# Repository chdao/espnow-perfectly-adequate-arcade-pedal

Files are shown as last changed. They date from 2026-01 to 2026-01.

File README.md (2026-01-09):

# ESPNow Perfectly Adequate Arcade Pedal

A wireless pedal system using ESP-NOW for low-latency communication between pedal transmitters and a USB HID keyboard receiver. Perfectly adequate for arcade gaming!

**Original Design**: This project is based on the [Perfectly Adequate Arcade Pedal (Wireless)](https://www.printables.com/model/1220746-perfectly-adequate-arcade-pedal-wireless) design on Printables. All initial ideas and the pedal model come from that design.

**PCB Project**: The custom PCB design is called **PanicPedal Pro** and includes an ESP32-S3-WROOM with automatic pedal detection. See `kicad-pcb/` for the KiCad project files and `esp32/panicpedal-pro/` for the firmware.

**⚠️ IMPORTANT CORRECTION**: The original schematic shows TP4056 OUT+ connected to the 3V3 pin. This is **INCORRECT** and can damage the ESP32. The TP4056 OUT+ must connect to **VCC** instead. See the [Wiring Diagram](#wiring-diagram) section below for the correct connections.

## Overview

This project consists of:
- **Transmitters**: ESP32-based pedal devices that send key press/release events via ESP-NOW
  - **FireBeetle 2**: `esp32/firebeetle2/firebeetle2.ino` - Configurable single or dual pedal mode
  - **PanicPedal Pro**: `esp32/panicpedal-pro/panicpedal-pro.ino` - Custom PCB with automatic pedal detection (1 or 2 pedals)
- **Receiver**: ESP32-S2/S3 device that receives ESP-NOW messages and types keys via USB HID Keyboard (`esp32/receiver/receiver.ino`)

**Note**: `espnow-pedal.cpp` is included as a reference file showing the original implementation. The actual project files are in the `esp32/` directory.

## Features

- **Low latency**: ESP-NOW provides fast, direct communication without WiFi connection
- **Multiple pedal modes**: Supports single pedal (LEFT or RIGHT) or dual pedal configurations
- **Automatic pedal detection** (PanicPedal Pro): Automatically detects whether 1 or 2 pedals are connected using NC (normally-closed) contacts - no manual configuration needed
- **Press and hold**: Keys stay pressed until pedal is released
- **Independent operation**: Both pedals can be pressed simultaneously
- **Battery efficient**: Includes inactivity timeout and deep sleep support
- **Automatic discovery**: No manual MAC address configuration needed - transmitters automatically discover receivers
- **Automatic reconnection**: Transmitters automatically reconnect to receivers after reboot
- **Slot management**: Receiver tracks available slots and only accepts transmitters when slots are available
- **Grace period**: 30-second discovery period after receiver boot for initial pairing and verification

## Hardware Requirements

### Recommended Boards

**Transmitters:**
- [FireBeetle 2 ESP32-E](https://www.dfrobot.com/product-2195.html) - Optimized for low power consumption, ideal for battery-powered pedal transmitters
- **PanicPedal Pro** - Custom PCB project with ESP32-S3-WROOM featuring automatic pedal detection (see `esp32/panicpedal-pro/README.md` for details)

**Receiver:**
- [ESP32-S3-DevKitC-1-N16R8](https://www.amazon.com/dp/B0CC8NYXRG) - ESP32-S3 board with native USB support for HID Keyboard functionality

### Transmitter
- ESP32 (tested with FireBeetle 2 ESP32-E and ESP32-S3-WROOM for PanicPedal Pro)
- Pedal switches (normally-open, connected to GPIO with pull-up)
- Optional: LED for status indication
- **PanicPedal Pro**: Uses NC (normally-closed) contacts for automatic detection of connected pedals

### Receiver
- ESP32-S2 or ESP32-S3 (for USB HID Keyboard support)
- USB connection to computer

## Pin Configuration

### Transmitter
- **Single Pedal Mode**: Connect pedal switch to GPIO 13
- **Dual Pedal Mode**: 
  - LEFT pedal: GPIO 13
  - RIGHT pedal: GPIO 14
- **LED**: GPIO 2 (optional)

**Pinout Reference**: See [FireBeetle 2 ESP32-E Pinout](docs/FireBeetle2_ESP32-E_Pinout.md) for complete pin details.

### Receiver
- Uses USB for communication (no GPIO pins needed for functionality)

## Wiring Diagram

### Transmitter Power Wiring (FireBeetle 2 ESP32-E)

**⚠️ IMPORTANT**: The TP4056 charging board OUT+ must connect to **VCC**, NOT 3V3!

```
TP4056 Charging Board          FireBeetle 2 ESP32-E
─────────────────────          ─────────────────────
OUT+ (red wire)    ──────────> VCC (or PH2.0 battery connector)
OUT- (black wire)  ──────────> GND
B+                 ──────────> 18650 Battery +
B-                 ──────────> 18650 Battery -
IN+                ──────────> Power Switch
IN-                ──────────> GND
```

**Why VCC and not 3V3?**
- **VCC** is the input voltage pin that accepts battery voltage (3.7-4.2V) or USB voltage (~4.7V)
- **3V3** is a regulated 3.3V OUTPUT pin - connecting 4-5V to it can damage the ESP32
- The FireBeetle's onboard regulator converts VCC to 3.3V internally

### Transmitter Signal Wiring

```
Left Pedal Switch (NO)  ───> GPIO 13
Left Pedal Switch (COM) ───> GND

Right Pedal Switch (NO)  ───> GPIO 14 (dual mode only)
Right Pedal Switch (COM) ───> GND

LED (anode)            ───> GPIO 2 (optional)
LED (cathode)          ───> GND
```

**Note**: The original schematic may show a "Mode Select Switch" on GPIO 26 for selecting between Bluetooth and ESP-NOW modes. This code uses ESP-NOW only, so that switch is not needed. Pedal mode (single/dual) is configured via the `PEDAL_MODE` define in the code.

**Note**: Switches should be normally-open (NO) type. The ESP32's internal pull-up resistors keep the pins HIGH when switches are open, and LOW when pressed.

## Setup and Usage

For detailed setup instructions, usage guide, configuration options, debug monitor setup, and troubleshooting, see [INSTRUCTIONS.md](INSTRUCTIONS.md).

## License

This project is provided as-is for educational and personal use.

## Contributing

Feel free to submit issues or pull requests for improvements!

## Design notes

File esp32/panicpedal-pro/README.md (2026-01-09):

# PanicPedal Pro Transmitter

This directory contains the firmware for the **PanicPedal Pro** transmitter PCB.

## Hardware

- **MCU**: ESP32-S3-WROOM
- **PCB**: Custom PanicPedal Pro PCB

## GPIO Pin Configuration

| GPIO | Function | Component |
|---|---|---|
| GPIO1 | Pedal Left NO | Left pedal normally-open contact |
| GPIO2 | Pedal Right NO | Right pedal normally-open contact |
| GPIO3 | Battery Voltage Sensing | Before TLV75733PDBV regulator |
| GPIO4 | STAT1/LBO | MCP73871 battery charger (charging status) |
| GPIO5 | Switch Position 1 | Single pole double throw switch position 1 |
| GPIO6 | Switch Position 2 | Single pole double throw switch position 2 |
| GPIO7 | LED DIN | APA102-2020 LED data input |
| GPIO35 | Pedal Left NC | Left pedal normally-closed contact (for detection) |
| GPIO36 | Pedal Right NC | Right pedal normally-closed contact (for detection) |
| GPIO41 | LED CLK | APA102-2020 LED clock |

## Configuration

- **Pedal Mode**: Auto-detected on every boot
  - Detection runs automatically on every boot to ensure correct configuration
  - If both switches are connected: Dual pedal mode (GPIO1 & GPIO2)
  - If only left switch is connected: Single pedal mode (GPIO1)
  - Detection uses NC contacts (GPIO35 & GPIO36) to sense switch presence
  - No NVS storage - always detects fresh on boot for maximum reliability
- **Manual Override**: Set `PEDAL_MODE` to `PEDAL_MODE_DUAL` (0) or `PEDAL_MODE_SINGLE` (1) to override auto-detection
- **Deep Sleep Wakeup**: GPIO1 (LOW trigger)

## Building and Uploading

1. Open `panicpedal-pro.ino` in Arduino IDE
2. Select your ESP32-S3 board from the board manager
3. Configure upload settings for your ESP32-S3-WROOM module
4. Upload the sketch

**Note**: Pedal detection runs automatically on every boot - no configuration needed!

## Notes

- This code is specifically designed for the PanicPedal Pro PCB
- **Automatic Switch Detection**: The firmware automatically detects which switches are connected by reading the NC (normally-closed) contacts on GPIO35 and GPIO36
  - No need to manually configure pedal mode - it's detected at boot
  - If a switch is connected, its NC contact will read LOW
  - This eliminates the need to hardcode pedal configuration
- Two foot switches can be connected:
  - Left pedal: NO on GPIO1, NC on GPIO35
  - Right pedal: NO on GPIO2, NC on GPIO36
- Battery monitoring pins (GPIO3, GPIO4) are available
- **LED Control**: APA102-2020 LED is fully implemented with status indicators:
  - **Blinking Blue**: Searching for receiver (pairing mode)
  - **Off**: Paired with receiver (LED off to save battery)
  - **Solid Green**: Battery is charging (detected via GPIO4 STAT1/LBO from MCP73871)
  - **Blinking Red**: Error state
  - **Note**: LED does not flash on pedal press to maximize battery life

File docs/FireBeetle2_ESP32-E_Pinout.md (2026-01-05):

# FireBeetle 2 ESP32-E Pinout Reference

This document describes the pinout for the FireBeetle 2 ESP32-E development board (ESP32-WROOM-32E module).

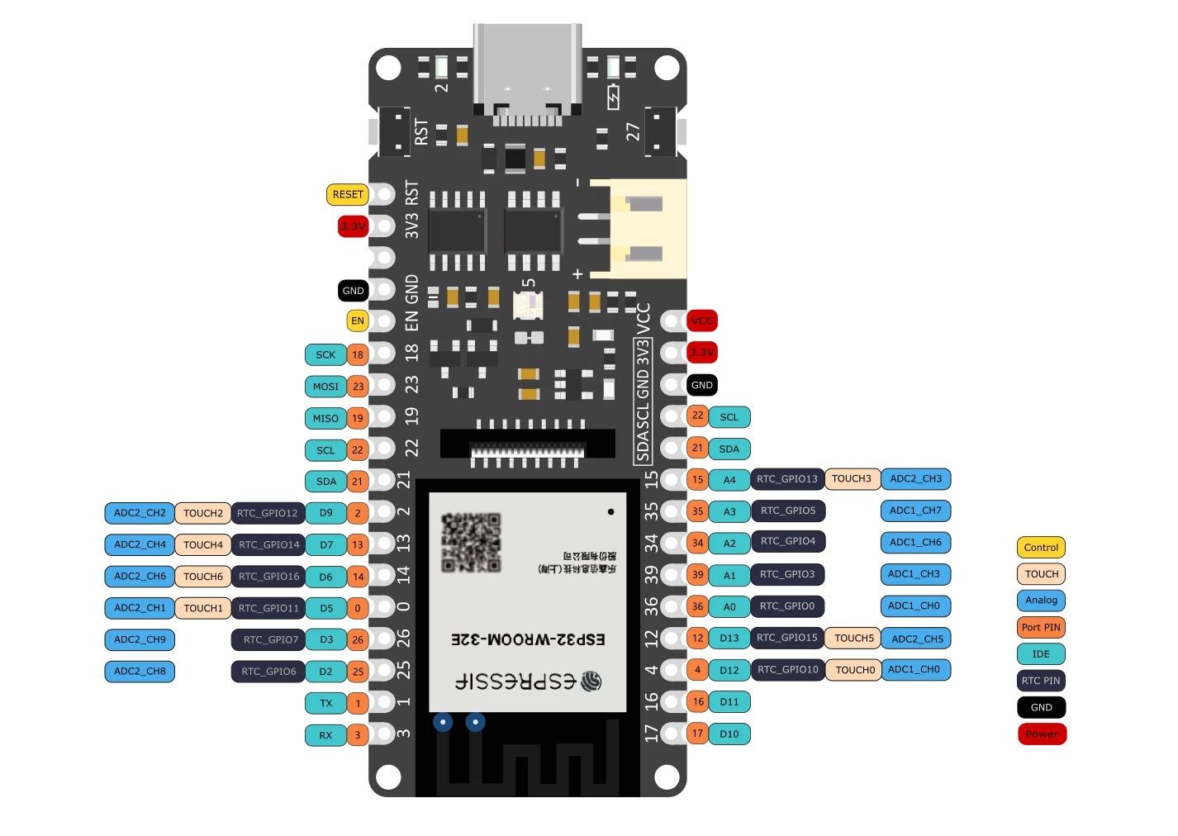
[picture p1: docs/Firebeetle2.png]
FireBeetle 2 ESP32-E Pinout


## Power Pins

- **VCC** (Red): Power input pin. Connect TP4056 OUT+ or battery here. Accepts 3.7-4.2V from battery or ~4.7V from USB.
- **3.3V** (Red): Regulated 3.3V OUTPUT pin. Do NOT connect battery voltage here - this is an output, not an input!
- **GND** (Black): Ground connection. Multiple GND pins available.

## GPIO Pins Used in This Project

### Left Pedal / Single Pedal
- **GPIO 13** (D7): Used for LEFT pedal in dual mode, or single pedal in single pedal mode
  - Also functions as: ADC2_CH4, TOUCH4, RTC_GPIO14
  - Supports deep sleep wakeup

### Right Pedal (Dual Mode Only)
- **GPIO 14** (D6): Used for RIGHT pedal in dual mode
  - Also functions as: ADC2_CH6, TOUCH6, RTC_GPIO16
  - Supports deep sleep wakeup

### LED (Optional)
- **GPIO 2** (D9): Used for status LED
  - Also functions as: ADC2_CH2, TOUCH2, RTC_GPIO12
  - Supports deep sleep wakeup

### Not Used (But Mentioned in Original Schematic)
- **GPIO 26** (D3): Mode Select Switch pin from original schematic
  - Not used in ESP-NOW only version
  - Also functions as: ADC2_CH9, RTC_GPIO7

## Other Available GPIO Pins

### SPI Pins
- **GPIO 18** (SCK): SPI Clock
- **GPIO 23** (MOSI): SPI Master Out Slave In
- **GPIO 19** (MISO): SPI Master In Slave Out

### I2C Pins
- **GPIO 22** (SCL): I2C Clock
- **GPIO 21** (SDA): I2C Data

### UART Pins
- **GPIO 1** (TX): UART Transmit
- **GPIO 3** (RX): UART Receive

### Analog Input Pins
- **GPIO 0** (D5): ADC2_CH1, TOUCH1, RTC_GPIO11
  - **⚠️ IMPORTANT**: Must be grounded (connected to GND) to enter download/boot mode for uploading sketches
- **GPIO 2** (D9): ADC2_CH2, TOUCH2, RTC_GPIO12 (LED pin)
- **GPIO 4** (D12): ADC1_CH0, TOUCH0, RTC_GPIO10
- **GPIO 12** (D13): ADC2_CH5, TOUCH5, RTC_GPIO15
- **GPIO 13** (D7): ADC2_CH4, TOUCH4, RTC_GPIO14 (Pedal pin)
- **GPIO 14** (D6): ADC2_CH6, TOUCH6, RTC_GPIO16 (Pedal pin)
- **GPIO 15** (A4): ADC2_CH3, TOUCH3, RTC_GPIO13
- **GPIO 25** (D2): ADC2_CH8, RTC_GPIO6
- **GPIO 26** (D3): ADC2_CH9, RTC_GPIO7
- **GPIO 27** (A5): ADC2_CH7, TOUCH7, RTC_GPIO17
- **GPIO 32** (A6): ADC1_CH4, RTC_GPIO9
- **GPIO 33** (A7): ADC1_CH5, RTC_GPIO8
- **GPIO 34** (A2): ADC1_CH6, RTC_GPIO4 (Input only)
- **GPIO 35** (A3): ADC1_CH7, RTC_GPIO5 (Input only)
- **GPIO 36** (A0): ADC1_CH0, RTC_GPIO0 (Input only)
- **GPIO 39** (A1): ADC1_CH3, RTC_GPIO3 (Input only)

### Control Pins
- **EN**: Enable pin (yellow)
- **RESET**: Reset button (yellow)

## Pin Categories

- **Control**: Yellow pins (EN, RESET)
- **TOUCH**: Beige pins (capacitive touch capable)
- **Analog**: Light blue pins (ADC capable)
- **Port PIN**: Orange pins (general purpose I/O)
- **IDE**: Blue pins (commonly used for SPI, I2C, UART)
- **RTC PIN**: Dark blue pins (retain state during deep sleep)
- **GND**: Black pins (ground)
- **Power**: Red pins (VCC input, 3.3V output)

## Important Notes

1. **VCC vs 3.3V**: Always connect battery/TP4056 OUT+ to **VCC**, never to 3.3V. The 3.3V pin is an output, not an input.

2. **Download Mode (GPIO 0)**: To upload sketches to the FireBeetle, GPIO 0 (D5) must be grounded (connected to GND) during the upload process. See the main README for detailed instructions.

3. **Deep Sleep Wakeup**: GPIO 13 and GPIO 14 support deep sleep wakeup, which is why they're used for the pedals.

4. **Input-Only Pins**: GPIO 34, 35, 36, and 39 are input-only (no internal pull-up/pull-down resistors).

5. **RTC Pins**: Pins marked as RTC can retain their state during deep sleep, which is useful for wakeup functionality.

## Reference

This pinout is based on the FireBeetle 2 ESP32-E development board featuring the ESP32-WROOM-32E module.

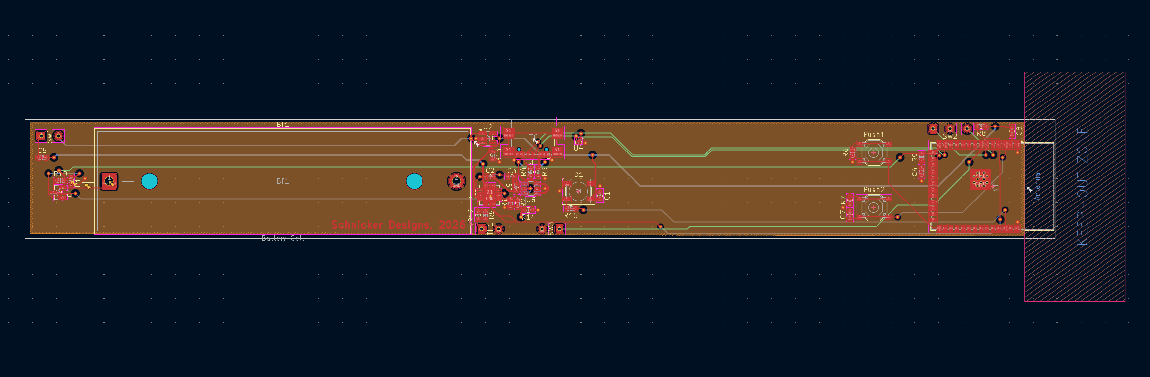
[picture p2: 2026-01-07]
docs/PCB_routing.png

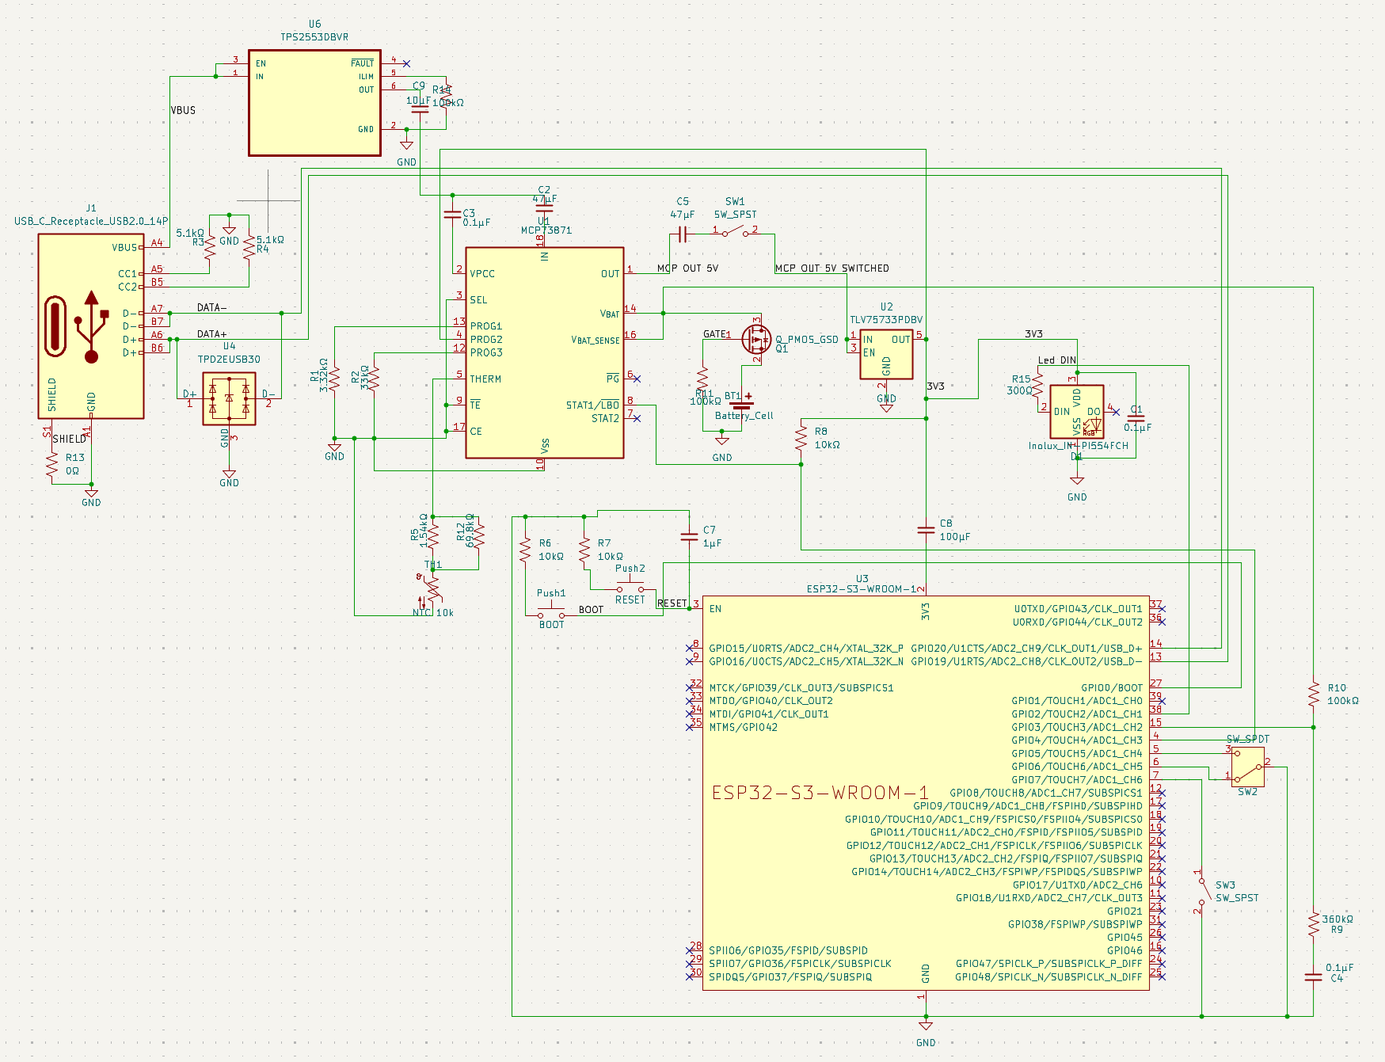
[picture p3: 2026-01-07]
docs/schema.png

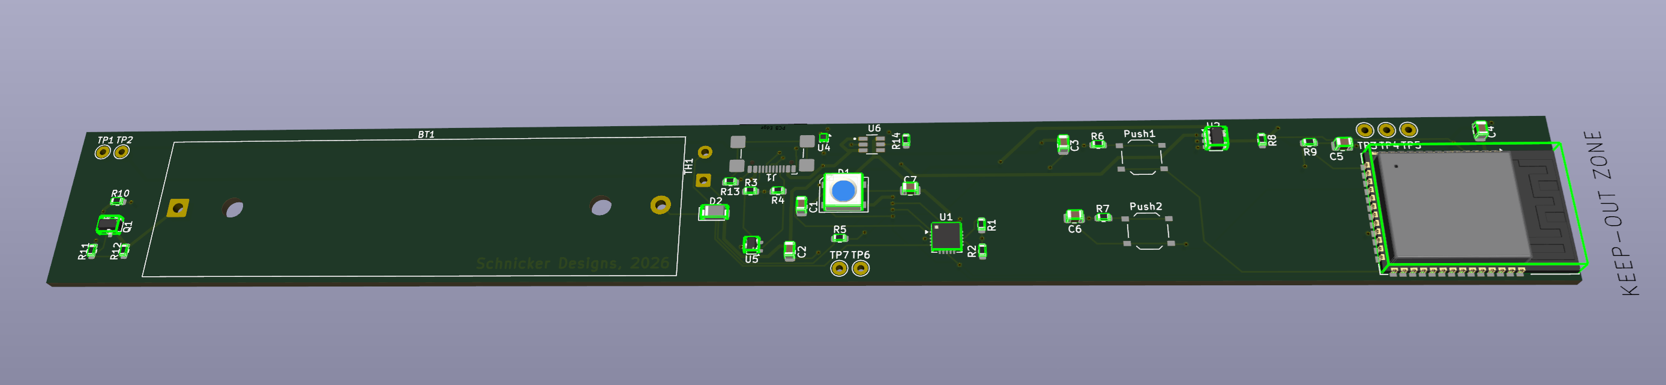
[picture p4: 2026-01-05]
docs/3D_render.png

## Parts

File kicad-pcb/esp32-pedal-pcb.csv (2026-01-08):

Reference | Qty | Value | DNP | Exclude from BOM | Exclude from Board | Footprint | Datasheet
BT1 | 1 | Battery_Cell |  |  |  | Battery:BatteryHolder_MPD_BH-18650-PC | ~
C1,C3,C4,C8,C11,C12,C13,C14 | 8 | 0.1µF |  |  |  | Capacitor_SMD:C_0603_1608Metric | ~
C2,C5 | 2 | 47µF |  |  |  | Capacitor_Tantalum_SMD:CP_EIA-7343-31_Kemet-D | ~
C6 | 1 | 100µF |  |  |  | Capacitor_Tantalum_SMD:CP_EIA-7343-31_Kemet-D | ~
C7,C10 | 2 | 1µF |  |  |  | Capacitor_SMD:C_0603_1608Metric | ~
C9 | 1 | 10µF |  |  |  | Capacitor_SMD:C_0603_1608Metric | ~
D1 | 1 | Inolux_IN-PI554FCH |  |  |  | LED_SMD:LED_Inolux_IN-PI554FCH_PLCC4_5.0x5.0mm_P3.2mm | http://www.inolux-corp.com/datasheet/SMDLED/Addressable%20LED/IN-PI554FCH.pdf
J1 | 1 | USB_C_Receptacle_USB2.0_14P |  |  |  | Connector_USB:USB_C_Receptacle_GCT_USB4110 | https://www.usb.org/sites/default/files/documents/usb_type-c.zip
J2,J3 | 2 | Conn_01x03 |  |  |  | Connector_Wire:SolderWire-0.1sqmm_1x03_P3.6mm_D0.4mm_OD1mm | ~
Push1 | 1 | BOOT |  |  |  | Button_Switch_SMD:SW_Push_1P1T_XKB_TS-1187A | ~
Push2 | 1 | RESET |  |  |  | Button_Switch_SMD:SW_Push_1P1T_XKB_TS-1187A | ~
Q1 | 1 | Q_PMOS_GSD |  |  |  | Package_TO_SOT_SMD:SOT-23 | ~
R1 | 1 | 3.32kΩ |  |  |  | Resistor_SMD:R_0603_1608Metric | ~
R2 | 1 | 33kΩ |  |  |  | Resistor_SMD:R_0603_1608Metric | ~
R3,R4 | 2 | 5.1kΩ |  |  |  | Resistor_SMD:R_0603_1608Metric | ~
R5 | 1 | 1.54kΩ |  |  |  | Resistor_SMD:R_0603_1608Metric | ~
R6,R7,R8,R16,R17,R18,R19 | 7 | 10kΩ |  |  |  | Resistor_SMD:R_0603_1608Metric | ~
R9 | 1 | 360kΩ |  |  |  | Resistor_SMD:R_0603_1608Metric | ~
R10,R11,R14 | 3 | 100kΩ |  |  |  | Resistor_SMD:R_0603_1608Metric | ~
R12 | 1 | 69.8kΩ |  |  |  | Resistor_SMD:R_0603_1608Metric | ~
R13 | 1 | 0Ω |  |  |  | Resistor_SMD:R_0603_1608Metric | ~
R15 | 1 | 300Ω |  |  |  | Resistor_SMD:R_0603_1608Metric | ~
SW1 | 1 | SW_SPST |  |  |  | Connector_Wire:SolderWire-0.1sqmm_1x02_P3.6mm_D0.4mm_OD1mm | ~
SW2 | 1 | SW_SPDT |  |  |  | Connector_Wire:SolderWire-0.1sqmm_1x03_P3.6mm_D0.4mm_OD1mm | ~
TH1 | 1 | NTC 10k |  |  |  | Connector_Wire:SolderWire-0.1sqmm_1x02_P3.6mm_D0.4mm_OD1mm | ~
U1 | 1 | MCP73871 |  |  |  | Package_DFN_QFN:QFN-20-1EP_4x4mm_P0.5mm_EP2.5x2.5mm | http://www.mouser.com/ds/2/268/22090a-52174.pdf
U2 | 1 | TLV75733PDBV |  |  |  | Package_TO_SOT_SMD:SOT-23-5 | https://www.ti.com/lit/ds/symlink/tlv757p.pdf
U3 | 1 | ESP32-S3-WROOM-1 |  |  |  | RF_Module:ESP32-S3-WROOM-1 | https://www.espressif.com/sites/default/files/documentation/esp32-s3-wroom-1_wroom-1u_datasheet_en.pdf
U4 | 1 | TPD2EUSB30 |  |  |  | Package_TO_SOT_SMD:Texas_DRT-3 | http://www.ti.com/lit/ds/symlink/tpd2eusb30a.pdf
U6 | 1 | TPS2553DBVR |  |  |  | TPS2553DBVR:SOT95P280X145-6N

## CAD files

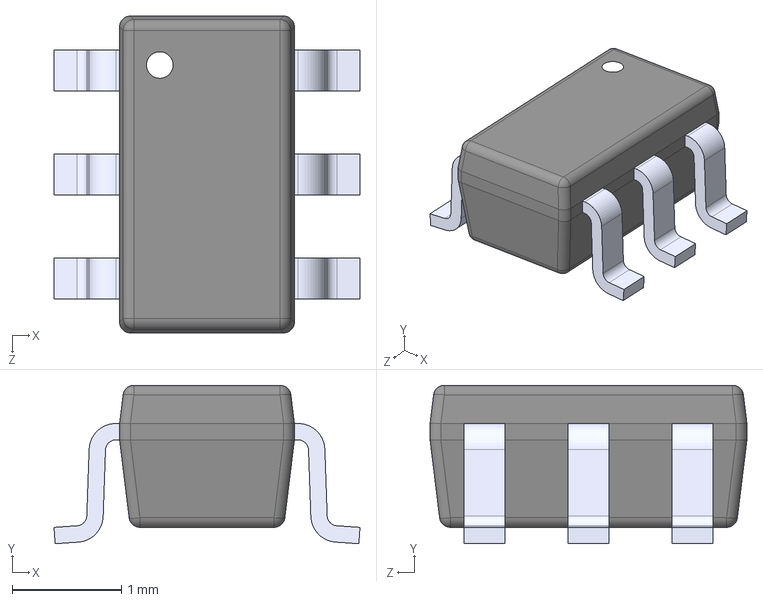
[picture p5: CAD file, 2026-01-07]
kicad-pcb/3dmodels/TPS2553DBVR.step
2.80 x 1.45 x 2.90 mm

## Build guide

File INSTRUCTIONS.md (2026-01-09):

# Setup and Usage Instructions

## Setup Instructions

### 0. Uploading Code to FireBeetle 2 ESP32-E

**⚠️ IMPORTANT**: To upload sketches to the FireBeetle 2 ESP32-E, you must ground GPIO 0 (D5) during upload:

1. Connect GPIO 0 (D5) to GND using a jumper wire or button
2. Press and hold the RESET button
3. While holding RESET, release GPIO 0 from GND (if using a button, release the button)
4. Release RESET button
5. The board should now be in download mode
6. Upload your sketch from Arduino IDE
7. After upload completes, disconnect GPIO 0 from GND

**Alternative method**: Some FireBeetle boards have a BOOT button that does this automatically. If your board has a BOOT button, hold BOOT while pressing RESET, then release RESET first, then release BOOT.

### 1. Configure Transmitter

**FireBeetle 2**: Open `esp32/firebeetle2/firebeetle2.ino` and set the pedal mode:

```cpp
#define PEDAL_MODE 1  // 0 = DUAL_PEDAL, 1 = SINGLE_PEDAL
```

**PanicPedal Pro**: No configuration needed! The firmware automatically detects whether 1 or 2 pedals are connected using the NC (normally-closed) contacts. Detection runs on every boot.

**Note**: The receiver automatically assigns keys based on pairing order:
- First paired transmitter: LEFT pedal ('l')
- Second paired transmitter: RIGHT pedal ('r')
- For DUAL mode transmitters: '1' maps to 'l', '2' maps to 'r'

### 2. Configure Receiver

The receiver requires no configuration - it automatically discovers and pairs with transmitters!

**LED Status Indicator** (ESP32-S3-DevKitC-1-N16R8):
- **Blue LED**: Receiver is in grace period (first 30 seconds after boot)
- **LED Off**: Normal operation after grace period

### 3. Upload Code

1. Upload `esp32/receiver/receiver.ino` to your ESP32-S2/S3 receiver board
2. Upload `esp32/firebeetle2/firebeetle2.ino` to your ESP32 transmitter board(s)
3. No MAC address configuration needed - everything is automatic!

## Usage

### Initial Pairing

1. **Power on the receiver first** - The receiver will start broadcasting availability beacons
2. **Power on the transmitter(s)** - Transmitters will automatically discover the receiver
3. **Press a pedal** - When you press a pedal for the first time, the transmitter will automatically pair with the receiver
4. The receiver LED will be blue during the 30-second grace period (discovery window)

### Normal Operation

- **Press pedals to type keys** - Keys stay pressed until pedal is released
- **Both pedals can be pressed simultaneously** (for dual pedal mode)
- **Automatic reconnection** - If a transmitter reboots, it will automatically reconnect to its paired receiver
- **Slot management** - The receiver supports up to 2 pedal slots total (e.g., 2 single pedals or 1 dual pedal)

### Discovery and Pairing Process

**How it works:**
1. **Receiver broadcasts beacons** during the first 30 seconds after boot, announcing its MAC address and available slots
2. **Transmitter learns receiver MAC** from beacon messages (only stores MAC if receiver has free slots)
3. **Transmitter sends discovery request** when pedal is pressed (if not already paired)
4. **Receiver responds** with discovery response to complete pairing
5. **Transmitter broadcasts pairing** so other receivers know it's taken

**Automatic Reconnection:**
- When a transmitter boots, it broadcasts its MAC address (`MSG_TRANSMITTER_ONLINE`)
- If the receiver recognizes the transmitter (from previous pairing), it immediately sends an `MSG_ALIVE` message
- The transmitter can then automatically reconnect without needing to press a pedal

**Grace Period:**
- First 30 seconds after receiver boot
- Receiver broadcasts availability beacons every 2 seconds
- Receiver pings known transmitters that haven't been seen yet
- LED indicator shows blue during grace period

## Configuration Options

### Transmitter Settings

- `PEDAL_MODE`: Pedal configuration (0=DUAL, 1=SINGLE)
- `INACTIVITY_TIMEOUT`: Time before entering deep sleep (default: 10 minutes)
- `DEBOUNCE_DELAY`: Debounce delay in milliseconds (default: 20ms)
- `DEBUG_ENABLED`: Enable/disable Serial debug output (default: 0 for battery saving)
- `IDLE_DELAY_PAIRED`: Delay in loop when paired (default: 10ms for better responsiveness)
- `IDLE_DELAY_UNPAIRED`: Delay in loop when not paired (default: 200ms)

### Receiver Settings

- `MAX_PEDAL_SLOTS`: Maximum number of pedal slots (default: 2)
- `BEACON_INTERVAL`: Interval between beacon broadcasts during grace period (default: 2000ms)
- `TRANSMITTER_TIMEOUT`: Grace period duration (default: 30000ms = 30 seconds)

**Note**: Keys are automatically assigned by the receiver based on pairing order:
- First transmitter: LEFT pedal ('l')
- Second transmitter: RIGHT pedal ('r')

## Debug Monitor

Since the receiver uses USB HID Keyboard, Serial output is not available for debugging. The receiver includes a **debug monitor** feature that sends debug messages via ESP-NOW to a separate ESP32 device.

### Setup

1. **Upload debug monitor code** to a second ESP32 board:
   - Use `debug-monitor/debug-monitor.ino`
   - Any ESP32 board with Serial/USB support works (e.g., ESP32-S3-DevKitC-1)

2. **Power on the debug monitor** - It will automatically discover and pair with the receiver

3. **Open Serial Monitor** on the debug monitor board at 115200 baud to see debug messages

### How It Works

- The debug monitor sends a discovery request (`MSG_DEBUG_MONITOR_REQ`) via ESP-NOW broadcast
- The receiver automatically pairs with the debug monitor and saves its MAC address
- All `debugPrint()` messages from the receiver are sent to the debug monitor via ESP-NOW
- Messages are displayed on the Serial Monitor of the debug monitor device
- The receiver remembers the debug monitor across reboots

### Benefits

- **Real-time debugging** without interfering with USB HID Keyboard functionality
- **Wireless debugging** - no physical connection needed
- **Persistent pairing** - debug monitor reconnects automatically after receiver reboot
- **Timestamped messages** - all debug messages include timestamps (milliseconds since boot)

## Troubleshooting

### Transmitter not pairing
- **Power on receiver first** - Receiver must be broadcasting beacons
- **Check grace period** - Pairing happens automatically during the 30-second grace period after receiver boot
- **Check receiver slots** - Receiver may be full (2 slots already used)
- **Press pedal** - Transmitter pairs when pedal is pressed (if receiver discovered)
- **Enable debug** - Set `DEBUG_ENABLED 1` in transmitter to see pairing messages

### Keys not typing
- **Check pairing status** - Transmitter must be paired with receiver
- **Verify receiver is powered on** - Receiver must be running
- **Check slot availability** - Receiver may have reached maximum slots (2)
- **Ensure both devices are ESP32 variants** that support ESP-NOW

### Transmitter not reconnecting after reboot
- **Wait for grace period** - Receiver sends `MSG_ALIVE` during grace period
- **Check pairing persistence** - Receiver remembers paired transmitters across reboots
- **Enable debug** - Check Serial output to see if `MSG_TRANSMITTER_ONLINE` is being sent/received

### Serial Monitor not working on receiver
- This is expected when Keyboard is active on ESP32-S2/S3
- Keyboard functionality should still work
- **Use the debug monitor** - Upload `debug-monitor/debug-monitor.ino` to a second ESP32 board to receive debug messages wirelessly via ESP-NOW
- Debug messages are automatically sent to the paired debug monitor device

### Multiple key presses
- Adjust `DEBOUNCE_DELAY` if experiencing contact bounce
- Check pedal switch connections
- Default debounce delay is 20ms (optimized for most switches)

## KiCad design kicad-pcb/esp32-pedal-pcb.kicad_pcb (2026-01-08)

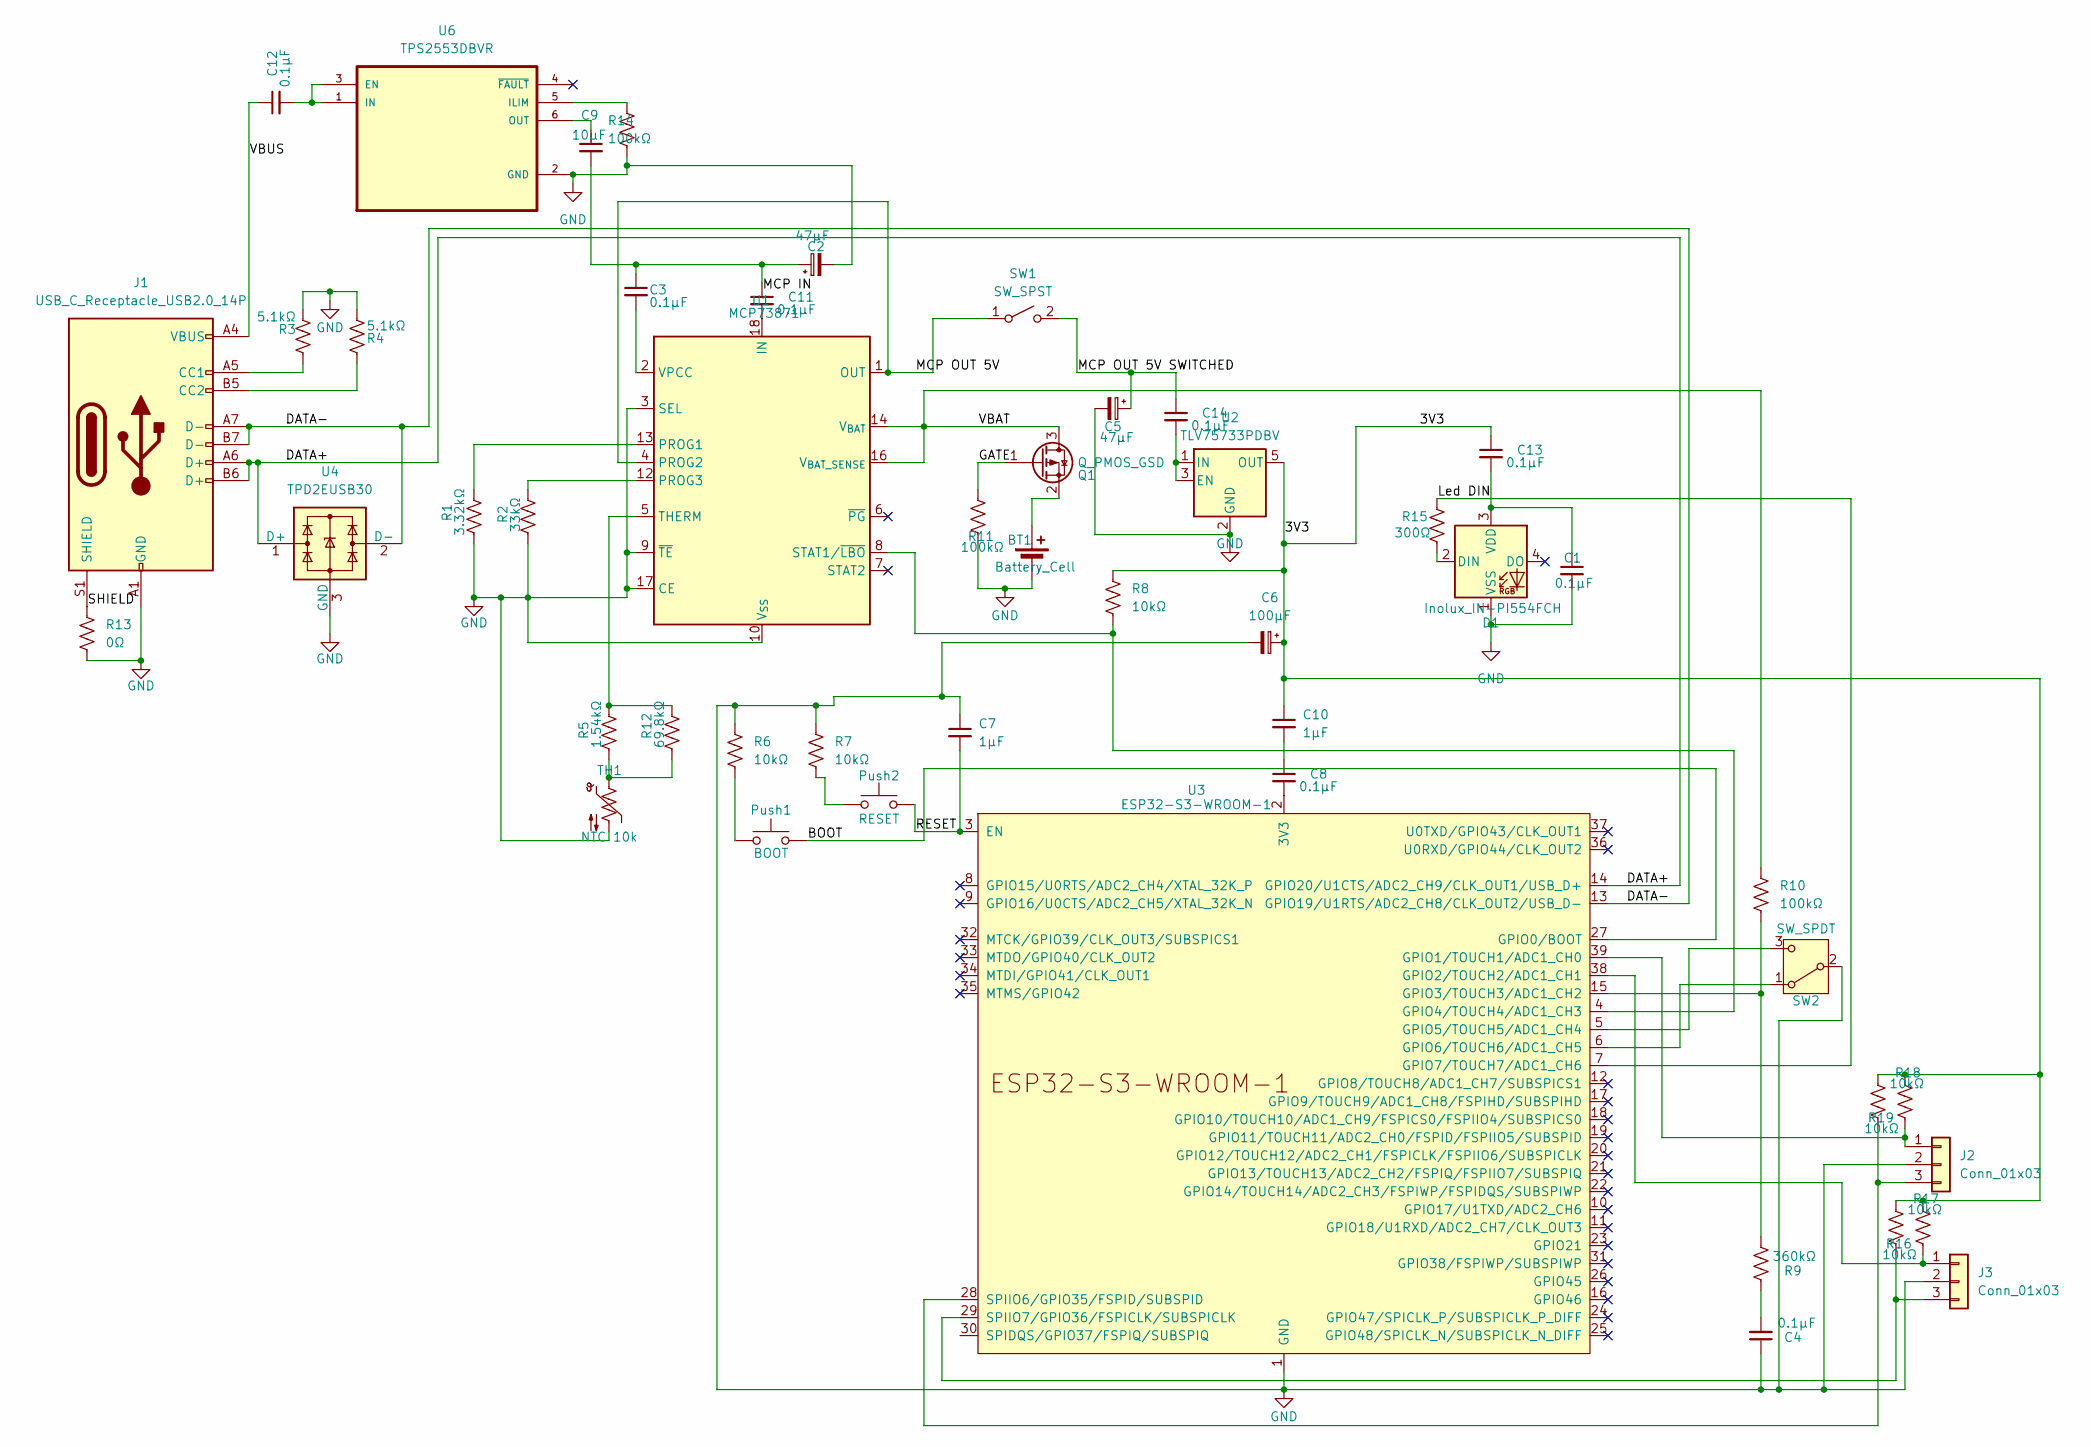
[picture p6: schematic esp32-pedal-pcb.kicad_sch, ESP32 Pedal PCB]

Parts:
BT1: Battery_Cell; BatteryHolder_MPD_BH-18650-PC
C1, C3, C4, C8, C11, C12, C13, C14: 0.1µF; C_0603_1608Metric
C2, C5: 47µF; CP_EIA-7343-31_Kemet-D
C6: 100µF; CP_EIA-7343-31_Kemet-D
C7, C10: 1µF; C_0603_1608Metric
C9: 10µF; C_0603_1608Metric
D1: Inolux_IN-PI554FCH; LED_Inolux_IN-PI554FCH_PLCC4_5.0x5.0mm_P3.2mm
J1: USB_C_Receptacle_USB2.0_14P; USB_C_Receptacle_GCT_USB4110
J2, J3: Conn_01x03; SolderWire-0.1sqmm_1x03_P3.6mm_D0.4mm_OD1mm
Push1: BOOT; SW_Push_1P1T_XKB_TS-1187A
Push2: RESET; SW_Push_1P1T_XKB_TS-1187A
Q1: Q_PMOS_GSD; SOT-23
R1: 3.32kΩ; R_0603_1608Metric
R2: 33kΩ; R_0603_1608Metric
R3, R4: 5.1kΩ; R_0603_1608Metric
R5: 1.54kΩ; R_0603_1608Metric
R6, R7, R8, R16, R17, R18, R19: 10kΩ; R_0603_1608Metric
R9: 360kΩ; R_0603_1608Metric
R10, R11, R14: 100kΩ; R_0603_1608Metric
R12: 69.8kΩ; R_0603_1608Metric
R13: 0Ω; R_0603_1608Metric
R15: 300Ω; R_0603_1608Metric
SW1: SW_SPST; SolderWire-0.1sqmm_1x02_P3.6mm_D0.4mm_OD1mm
SW2: SW_SPDT; SolderWire-0.1sqmm_1x03_P3.6mm_D0.4mm_OD1mm
TH1: NTC 10k; SolderWire-0.1sqmm_1x02_P3.6mm_D0.4mm_OD1mm
U1: MCP73871; QFN-20-1EP_4x4mm_P0.5mm_EP2.5x2.5mm
U2: TLV75733PDBV; SOT-23-5
U3: ESP32-S3-WROOM-1
U4: TPD2EUSB30; Texas_DRT-3
U6: TPS2553DBVR; SOT95P280X145-6N

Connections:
/3V3: C6.1, C10.1, C13.1, R8.1, R16.1, R17.1, R18.1, R19.1, U2.5 (OUT)
/BOOT: Push1.2, U3.27 (GPIO0/BOOT)
/DATA+: J1.A6 (D+), J1.B6 (D+), U3.14 (GPIO20/U1CTS/ADC2_CH9/CLK_OUT1/USB_D+), U4.1 (D+)
/DATA-: J1.A7 (D-), J1.B7 (D-), U3.13 (GPIO19/U1RTS/ADC2_CH8/CLK_OUT2/USB_D-), U4.2 (D-)
/GATE: Q1.1 (G), R11.1
/Led DIN: R15.1, U3.7 (GPIO7/TOUCH7/ADC1_CH6)
/MCP OUT 5V: SW1.1 (A), U1.1 (OUT), U1.4 (PROG2), U1.20 (OUT)
/MCP OUT 5V SWITCHED: C5.1, C14.1, SW1.2 (B)
/RESET: C7.2, Push2.2, U3.3 (EN)
/SHIELD: J1.S1 (SHIELD), R13.1
/VBAT: Q1.3 (D), R10.1, U1.14 (V_{BAT}), U1.15 (V_{BAT}), U1.16 (V_{BAT_SENSE})
/VBUS: C12.1, J1.A4 (VBUS), J1.A9 (VBUS), J1.B4 (VBUS), J1.B9 (VBUS)
GND: BT1.2 (-), C1.2, C2.2, C4.1, C5.2, C6.2, C7.1, D1.1 (VSS), J1.A1 (GND), J1.A12 (GND), J1.B1 (GND), J1.B12 (GND), J2.2, J3.2, R1.2, R2.2, R3.1, R4.1, R6.1, R7.1, R11.2, R13.2, R14.2, SW2.2 (B), TH1.2, U1.3 (SEL), U1.9 (~TE), U1.10 (V_{SS}), U1.11 (V_{SS}), U1.17 (CE), U1.21 (V_{SS}), U2.2 (GND), U3.1 (GND), U3.40 (GND), U3.41 (GND), U4.3 (GND), U6.2 (GND)
unnamed: BT1.1 (+), Q1.2 (S)
unnamed: C4.2, R9.1
unnamed: C8.1, C10.2
unnamed: C2.1, C3.1, C9.2, C11.1
unnamed: C11.2, U1.18 (IN), U1.19 (IN)
unnamed: D1.2 (DIN), R15.2
unnamed: C1.1, C13.2, D1.3 (VDD)
unnamed: J1.A5 (CC1), R3.2
unnamed: J1.B5 (CC2), R4.2
unnamed: J2.1, R18.2, U3.39 (GPIO1/TOUCH1/ADC1_CH0)
unnamed: J2.3, R19.2, U3.28 (SPIIO6/GPIO35/FSPID/SUBSPID)
unnamed: J3.1, R17.2, U3.38 (GPIO2/TOUCH2/ADC1_CH1)
unnamed: J3.3, R16.2, U3.29 (SPIIO7/GPIO36/FSPICLK/SUBSPICLK)
unnamed: Push1.1, R6.2
unnamed: Push2.1, R7.2
unnamed: R5.2, R12.2, TH1.1
unnamed: SW2.1 (A), U3.6 (GPIO6/TOUCH6/ADC1_CH5)
unnamed: SW2.3 (C), U3.5 (GPIO5/TOUCH5/ADC1_CH4)
unnamed: R1.1, U1.13 (PROG1)
unnamed: R2.1, U1.12 (PROG3)
unnamed: R8.2, U1.8 (STAT1/~LBO), U3.4 (GPIO4/TOUCH4/ADC1_CH3)
unnamed: R5.1, R12.1, U1.5 (THERM)
unnamed: C3.2, U1.2 (VPCC)
unnamed: C14.2, U2.1 (IN), U2.3 (EN)
unnamed: C8.2, U3.2 (3V3)
unnamed: R9.2, R10.2, U3.15 (GPIO3/TOUCH3/ADC1_CH2)
unnamed: C12.2, U6.1 (IN), U6.3 (EN)
unnamed: R14.1, U6.5 (ILIM)
unnamed: C9.1, U6.6 (OUT)

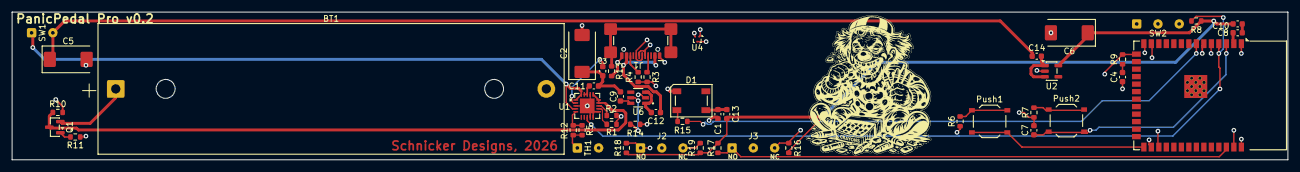
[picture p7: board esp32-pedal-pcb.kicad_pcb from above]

Board: 4 copper layers, 216.0 x 25.0 mm, 49 parts (0 on the bottom side), 42 nets.

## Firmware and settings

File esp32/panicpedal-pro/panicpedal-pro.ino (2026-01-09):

#include <Arduino.h>
#include <esp_now.h>
#include <WiFi.h>
#include "esp_wifi.h"

// Clean Architecture: Include shared and domain modules
#include "shared/messages.h"
#include "domain/PairingState.h"
#include "domain/PedalReader.h"
#include "infrastructure/EspNowTransport.h"
#include "application/PairingService.h"
#include "application/PedalService.h"

// ============================================================================
// CONFIGURATION
// ============================================================================
#define PEDAL_MODE_AUTO -1     // Auto-detect based on connected switches (recommended)
#define PEDAL_MODE_DUAL 0      // Force dual pedal mode (GPIO1 & GPIO2)
#define PEDAL_MODE_SINGLE 1    // Force single pedal mode (GPIO1 only)
#define PEDAL_MODE PEDAL_MODE_AUTO  // Change to PEDAL_MODE_DUAL or PEDAL_MODE_SINGLE to override auto-detection
#define DEBUG_ENABLED 1  // Set to 0 to disable Serial output and save battery
// ============================================================================

// GPIO Pin Definitions (PanicPedal Pro - ESP32-S3-WROOM)
#define PEDAL_LEFT_NO_PIN 1    // Left pedal switch NO (normally open)
#define PEDAL_RIGHT_NO_PIN 2   // Right pedal switch NO (normally open)
#define BATTERY_VOLTAGE_PIN 3  // Battery voltage sensing (before TLV75733PDBV)
#define BATTERY_STAT1_PIN 4    // STAT1/LBO from MCP73871 (charging status)
#define SWITCH_POS1_PIN 5      // Single pole double throw switch position 1
#define SWITCH_POS2_PIN 6      // Single pole double throw switch position 2
#define LED_DIN_PIN 7          // APA102-2020 LED DIN
#define LED_CLK_PIN 41         // APA102-2020 LED CLK
#define PEDAL_LEFT_NC_PIN 35   // Left pedal switch NC (normally closed) - for detection
#define PEDAL_RIGHT_NC_PIN 36  // Right pedal switch NC (normally closed) - for detection

#define INACTIVITY_TIMEOUT 600000  // 10 minutes
#define IDLE_DELAY_PAIRED 20  // 20ms delay when paired
#define IDLE_DELAY_UNPAIRED 200  // 200ms delay when not paired

// Domain layer instances
PairingState pairingState;
PedalReader pedalReader;
EspNowTransport transport;

// Application layer instances
PairingService pairingService;
PedalService pedalService;

// System state
unsigned long lastActivityTime = 0;
unsigned long bootTime = 0;

// Forward declarations
void onMessageReceived(const uint8_t* senderMAC, const uint8_t* data, int len, uint8_t channel);
void onPaired(const uint8_t* receiverMAC);
void onActivity();
uint8_t detectPedalMode();

void onPaired(const uint8_t* receiverMAC) {
  #if DEBUG_ENABLED
  Serial.print("[");
  Serial.print(millis() - bootTime);
  Serial.print(" ms] Successfully paired with receiver: ");
  for (int i = 0; i < 6; i++) {
    Serial.print(receiverMAC[i], HEX);
    if (i < 5) Serial.print(":");
  }
  Serial.println();
  #endif
}

void onActivity() {
  lastActivityTime = millis();
}

void sendDeleteRecordMessage(const uint8_t* receiverMAC) {
  struct_message deleteMsg = {MSG_DELETE_RECORD, 0, false, 0};
  espNowTransport_send(&transport, receiverMAC, (uint8_t*)&deleteMsg, sizeof(deleteMsg));
  #if DEBUG_ENABLED
  Serial.print("[");
  Serial.print(millis() - bootTime);
  Serial.print(" ms] Sent delete record message to receiver: ");
  for (int i = 0; i < 6; i++) {
    Serial.print(receiverMAC[i], HEX);
    if (i < 5) Serial.print(":");
  }
  Serial.println();
  #endif
}

void onMessageReceived(const uint8_t* senderMAC, const uint8_t* data, int len, uint8_t channel) {
  if (len < 1) return;
  
  #if DEBUG_ENABLED
  unsigned long timeSinceBoot = millis() - bootTime;
  Serial.print("[");
  Serial.print(timeSinceBoot);
  Serial.print(" ms] Received ESP-NOW message: len=");
  Serial.print(len);
  Serial.print(", sender=");
  for (int i = 0; i < 6; i++) {
    Serial.print(senderMAC[i], HEX);
    if (i < 5) Serial.print(":");
  }
  Serial.println();
  #endif
  
  uint8_t msgType = data[0];
  
  // Handle beacon message
  if (msgType == MSG_BEACON && len >= sizeof(beacon_message)) {
    beacon_message* beacon = (beacon_message*)data;
    pairingService_handleBeacon(&pairingService, senderMAC, beacon);
    
    #if DEBUG_ENABLED
    Serial.print("[");
    Serial.print(timeSinceBoot);
    Serial.print(" ms] Received MSG_BEACON: slots=");
    Serial.print(beacon->availableSlots);
    Serial.print("/");
    Serial.print(beacon->totalSlots);
    Serial.println();
    #endif
    return;
  }
  
  // Handle other messages
  if (len < sizeof(struct_message)) {
    #if DEBUG_ENABLED
    Serial.print("[");
    Serial.print(timeSinceBoot);
    Serial.println(" ms] Message too short");
    #endif
    return;
  }
  
  struct_message* msg = (struct_message*)data;
  
  #if DEBUG_ENABLED
  Serial.print("[");
  Serial.print(timeSinceBoot);
  Serial.print(" ms] Message type=");
  Serial.print(msg->msgType);
  Serial.print(", isPaired=");
  Serial.println(pairingState_isPaired(&pairingState));
  #endif
  
  if (pairingState_isPaired(&pairingState)) {
    // Already paired - check if message is from our paired receiver
    if (memcmp(senderMAC, pairingState.pairedReceiverMAC, 6) == 0) {
      // Message from our paired receiver - accept it
      #if DEBUG_ENABLED
      Serial.print("[");
      Serial.print(timeSinceBoot);
      Serial.print(" ms] Received message from paired receiver (type=");
      Serial.print(msg->msgType);
      Serial.println(")");
      #endif
    } else {
      // Message from different receiver - send DELETE_RECORD
      if (msg->msgType == MSG_ALIVE || msg->msgType == MSG_DISCOVERY_RESP) {
        #if DEBUG_ENABLED
        Serial.print("[");
        Serial.print(timeSinceBoot);
        Serial.println(" ms] Received message from different receiver - sending DELETE_RECORD");
        #endif
        
        espNowTransport_addPeer(&transport, senderMAC, channel);
        sendDeleteRecordMessage(senderMAC);
      }
    }
  } else {
    // Not paired - handle pairing messages
    if (msg->msgType == MSG_DISCOVERY_RESP) {
      pairingService_handleDiscoveryResponse(&pairingService, senderMAC, channel);
    } else if (msg->msgType == MSG_ALIVE) {
      pairingService_handleAlive(&pairingService, senderMAC, channel);
    }
  }
}


uint8_t detectPedalMode() {
  // Configure NC pins as inputs with pull-ups to detect switch connections
  pinMode(PEDAL_LEFT_NC_PIN, INPUT_PULLUP);
  pinMode(PEDAL_RIGHT_NC_PIN, INPUT_PULLUP);
  
  // Small delay to allow pins to stabilize
  delay(10);
  
  // Read NC pins - LOW means switch is connected (NC contact is grounded)
  bool pedal1Connected = (digitalRead(PEDAL_LEFT_NC_PIN) == LOW);
  bool pedal2Connected = (digitalRead(PEDAL_RIGHT_NC_PIN) == LOW);
  
  #if DEBUG_ENABLED
  Serial.print("Pedal detection: Pedal 1=");
  Serial.print(pedal1Connected ? "CONNECTED" : "NOT CONNECTED");
  Serial.print(", Pedal 2=");
  Serial.println(pedal2Connected ? "CONNECTED" : "NOT CONNECTED");
  #endif
  
  // Determine mode based on detected switches
  uint8_t detectedMode;
  if (pedal1Connected && pedal2Connected) {
    detectedMode = PEDAL_MODE_DUAL;
  } else if (pedal1Connected) {
    detectedMode = PEDAL_MODE_SINGLE;
  } else {
    // Default to single mode if no switches detected (fallback)
    detectedMode = PEDAL_MODE_SINGLE;
  }
  
  #if DEBUG_ENABLED
  Serial.print("Detected pedal mode: ");
  Serial.println(detectedMode == PEDAL_MODE_DUAL ? "DUAL" : "SINGLE");
  #endif
  
  return detectedMode;
}

void goToDeepSleep() {
  #if DEBUG_ENABLED
  Serial.println("Going to deep sleep...");
  #endif
  esp_sleep_enable_ext0_wakeup((gpio_num_t)PEDAL_LEFT_NO_PIN, LOW);
  esp_deep_sleep_start();
}

void setup() {
  #if DEBUG_ENABLED
  Serial.begin(115200);
  delay(100);
  Serial.println("ESP-NOW Pedal Transmitter - PanicPedal Pro");
  #endif

  // Battery optimization
  setCpuFrequencyMhz(80);
  esp_wifi_set_ps(WIFI_PS_MAX_MODEM);
  
  bootTime = millis();
  lastActivityTime = millis();
  
  // Determine pedal mode - detect on every boot
  uint8_t detectedMode = PEDAL_MODE;
  
  if (PEDAL_MODE == PEDAL_MODE_AUTO) {
    // Auto-detect pedal mode on every boot
    detectedMode = detectPedalMode();
    #if DEBUG_ENABLED
    Serial.print("Auto-detected mode: ");
    Serial.println(detectedMode == PEDAL_MODE_DUAL ? "DUAL (GPIO1 & GPIO2)" : "SINGLE (GPIO1)");
    #endif
  } else {
    // Manual override mode
    #if DEBUG_ENABLED
    Serial.print("Mode (manual override): ");
    Serial.println(detectedMode == PEDAL_MODE_DUAL ? "DUAL (GPIO1 & GPIO2)" : "SINGLE (GPIO1)");
    #endif
  }
  
  // Initialize domain layer
  pairingState_init(&pairingState);
  pedalReader_init(&pedalReader, PEDAL_LEFT_NO_PIN, PEDAL_RIGHT_NO_PIN, detectedMode);
  
  // Initialize infrastructure layer
  espNowTransport_init(&transport);
  
  // Add broadcast peer
  uint8_t broadcastMAC[] = BROADCAST_MAC;
  espNowTransport_addPeer(&transport, broadcastMAC, 0);
  espNowTransport_registerReceiveCallback(&transport, onMessageReceived);
  
  // Initialize application layer
  pairingService_init(&pairingService, &pairingState, &transport, detectedMode, bootTime);
  pairingService.onPaired = onPaired;
  
  pedalService_init(&pedalService, &pedalReader, &pairingState, &transport, &lastActivityTime);
  pedalService.onActivity = onActivity;
  pedalService_setPairingService(&pairingService);
  
  // Broadcast that we're online
  pairingService_broadcastOnline(&pairingService);
  
  #if DEBUG_ENABLED
  Serial.println("ESP-NOW initialized");
  #endif
}

void loop() {
  unsigned long currentTime = millis();
  
  // Check discovery timeout
  if (pairingService_checkDiscoveryTimeout(&pairingService, currentTime)) {
    #if DEBUG_ENABLED
    Serial.println("Discovery response timeout");
    #endif
  }
  
  // Check inactivity timeout
  if (currentTime - lastActivityTime > INACTIVITY_TIMEOUT) {
    goToDeepSleep();
  }
  
  // Update pedal service (handles pedal reading and events)
  pedalService_update(&pedalService);
  
  // Battery optimization: Variable delay based on pairing status
  if (pairingState_isPaired(&pairingState)) {
    delay(IDLE_DELAY_PAIRED);
  } else {
    delay(IDLE_DELAY_UNPAIRED);
  }
}

// Include implementation files (Arduino IDE doesn't auto-compile .cpp files in subdirectories)
#include "domain/PairingState.cpp"
#include "domain/PedalReader.cpp"
#include "infrastructure/EspNowTransport.cpp"
#include "application/PairingService.cpp"
#include "application/PedalService.cpp"

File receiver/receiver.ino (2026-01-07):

#include <WiFi.h>
#include <esp_now.h>

// Clean Architecture: Include shared and domain modules
#include "shared/messages.h"
#include "domain/TransmitterManager.h"
#include "infrastructure/EspNowTransport.h"
#include "infrastructure/Persistence.h"
#include "infrastructure/LEDService.h"
#include "infrastructure/DebugMonitor.h"
#include "application/PairingService.h"
#include "application/KeyboardService.h"

// Domain layer instances
TransmitterManager transmitterManager;
ReceiverEspNowTransport transport;
LEDService ledService;
DebugMonitor debugMonitor;

// Application layer instances
ReceiverPairingService pairingService;
KeyboardService keyboardService;

// System state
unsigned long bootTime = 0;

// Forward declaration
void onMessageReceived(const uint8_t* senderMAC, const uint8_t* data, int len, uint8_t channel);

void onMessageReceived(const uint8_t* senderMAC, const uint8_t* data, int len, uint8_t channel) {
  if (len < 1) return;
  
  uint8_t msgType = data[0];
  
  // Handle debug monitor discovery request
  if (msgType == MSG_DEBUG_MONITOR_REQ) {
    debugMonitor_handleDiscoveryRequest(&debugMonitor, senderMAC, channel);
    
    // Send immediate confirmation that pairing succeeded
    debugMonitor_print(&debugMonitor, "Debug monitor discovery request received and processed");
    return;
  }
  
  // Handle transmitter online broadcast
  if (len >= sizeof(transmitter_online_message)) {
    transmitter_online_message* onlineMsg = (transmitter_online_message*)data;
    if (onlineMsg->msgType == MSG_TRANSMITTER_ONLINE) {
      int index = transmitterManager_findIndex(&transmitterManager, senderMAC);
      if (index >= 0) {
        debugMonitor_print(&debugMonitor, "Received MSG_TRANSMITTER_ONLINE from known transmitter %d", index);
      } else {
        debugMonitor_print(&debugMonitor, "Received MSG_TRANSMITTER_ONLINE from unknown transmitter");
      }
      receiverPairingService_handleTransmitterOnline(&pairingService, senderMAC, channel);
      return;
    }
  }
  
  // Handle transmitter paired broadcast
  if (len >= sizeof(transmitter_paired_message)) {
    transmitter_paired_message* pairedMsg = (transmitter_paired_message*)data;
    if (pairedMsg->msgType == MSG_TRANSMITTER_PAIRED) {
      debugMonitor_print(&debugMonitor, "Received MSG_TRANSMITTER_PAIRED");
      receiverPairingService_handleTransmitterPaired(&pairingService, pairedMsg);
      return;
    }
  }
  
  // Handle standard messages
  if (len < sizeof(struct_message)) return;
  
  struct_message* msg = (struct_message*)data;
  
  switch (msg->msgType) {
    case MSG_DELETE_RECORD: {
      int index = transmitterManager_findIndex(&transmitterManager, senderMAC);
      if (index >= 0) {
        debugMonitor_print(&debugMonitor, "Received delete record request from transmitter %d - removing", index);
        transmitterManager_remove(&transmitterManager, index);
        persistence_save(&transmitterManager);
      }
      break;
    }
    
    case MSG_DISCOVERY_REQ: {
      debugMonitor_print(&debugMonitor, "Discovery request from %02X:%02X:%02X:%02X:%02X:%02X (mode=%d)",
                         senderMAC[0], senderMAC[1], senderMAC[2], senderMAC[3], senderMAC[4], senderMAC[5], msg->pedalMode);
      receiverPairingService_handleDiscoveryRequest(&pairingService, senderMAC, msg->pedalMode, channel, millis());
      persistence_save(&transmitterManager);
      break;
    }
    
    case MSG_PEDAL_EVENT: {
      int transmitterIndex = transmitterManager_findIndex(&transmitterManager, senderMAC);
      if (transmitterIndex >= 0) {
        char keyToPress;
        if (transmitterManager.transmitters[transmitterIndex].pedalMode == 0) {
          keyToPress = (msg->key == '1') ? 'l' : 'r';
        } else {
          keyToPress = transmitterManager_getAssignedKey(&transmitterManager, transmitterIndex);
        }
        debugMonitor_print(&debugMonitor, "Pedal event: transmitter %d, key '%c' %s", 
                          transmitterIndex, keyToPress, msg->pressed ? "PRESSED" : "RELEASED");
      }
      keyboardService_handlePedalEvent(&keyboardService, senderMAC, msg);
      break;
    }
    
    case MSG_ALIVE: {
      receiverPairingService_handleAlive(&pairingService, senderMAC);
      break;
    }
  }
}

void setup() {
  bootTime = millis();
  
  // Initialize domain layer
  transmitterManager_init(&transmitterManager);
  
  // Initialize infrastructure layer first (needed for debug monitor)
  receiverEspNowTransport_init(&transport);
  debugMonitor_init(&debugMonitor, &transport, bootTime);
  debugMonitor_load(&debugMonitor);
  debugMonitor.espNowInitialized = true;
  
  // Load persisted state
  persistence_load(&transmitterManager);
  
  ledService_init(&ledService, bootTime);
  
  // Initialize application layer
  receiverPairingService_init(&pairingService, &transmitterManager, &transport, bootTime);
  keyboardService_init(&keyboardService, &transmitterManager);
  
  // Register message callback (must be before adding peers)
  receiverEspNowTransport_registerReceiveCallback(&transport, onMessageReceived);
  
  // Add broadcast peer
  uint8_t broadcastMAC[] = BROADCAST_MAC;
  receiverEspNowTransport_addPeer(&transport, broadcastMAC, 0);
  
  // Add saved transmitters as peers
  for (int i = 0; i < transmitterManager.count; i++) {
    receiverEspNowTransport_addPeer(&transport, transmitterManager.transmitters[i].mac, 0);
  }
  
  // Add saved debug monitor as peer (if it was saved)
  if (debugMonitor.paired) {
    receiverEspNowTransport_addPeer(&transport, debugMonitor.mac, 0);
    // Small delay to ensure peer is ready before sending messages
    delay(50);
    
    // Send debug messages now that ESP-NOW is fully initialized
    debugMonitor_print(&debugMonitor, "ESP-NOW initialized");
    debugMonitor_print(&debugMonitor, "Loaded %d transmitter(s) from EEPROM", transmitterManager.count);
    debugMonitor_print(&debugMonitor, "Pedal slots used: %d/%d", transmitterManager.slotsUsed, MAX_PEDAL_SLOTS);
  }
  
  debugMonitor_print(&debugMonitor, "=== Receiver Ready ===");
}

void loop() {
  unsigned long currentTime = millis();
  
  // Update pairing service (handles beacons, pings, replacement logic)
  receiverPairingService_update(&pairingService, currentTime);
  
  // Update LED status
  ledService_update(&ledService, currentTime);
  
  delay(10);
}

// Include implementation files (Arduino IDE doesn't auto-compile .cpp files in subdirectories)
#include "domain/TransmitterManager.cpp"
#include "infrastructure/EspNowTransport.cpp"
#include "infrastructure/Persistence.cpp"
#include "infrastructure/LEDService.cpp"
#include "infrastructure/DebugMonitor.cpp"
#include "application/PairingService.cpp"
#include "application/KeyboardService.cpp"

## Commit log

2025-12-31 Fix MAC address output format to match transmitter (lowercase hex)
    [run-this-first.ino]
2025-12-31 Fix helper function to correctly print hex values
    [run-this-first.ino]
2025-12-31 Add link to original Printables design and credit
2026-01-01 Remove GPIO 26 Mode Select Switch reference - not used in ESP-NOW only code
2026-01-01 Add FireBeetle 2 ESP32-E pinout reference documentation
2026-01-01 Add FireBeetle 2 ESP32-E pinout diagram image
2026-01-01 Add heartbeat mechanism with exponential backoff and implicit heartbeats
    - Receiver sends alive messages every 30 seconds to paired transmitters
    - Transmitters detect connection loss if no message received for 35 seconds
    - Any message from receiver resets alive timer (implicit heartbeat)
    - Exponential backoff for reconnection: 5s, 10s, 20s, 30s (max)
    - Improved battery efficiency with longer intervals
    - First boot discovery times out after 10s to save battery
    - Reconnection attempts continue indefinitely with backoff
    [receiver.ino, transmitter.ino]
2026-01-02 Update README with automatic discovery and reconnection features
    - Document automatic discovery via beacons
    - Explain automatic reconnection after reboot
    - Remove manual MAC address configuration steps
    - Add grace period and LED status indicator documentation
    - Update troubleshooting section with new pairing/reconnection info
    - Simplify setup instructions
2026-01-02 Check for free slots before sending MSG_ALIVE on transmitter online
    - Receiver now checks if it has free slots before responding to MSG_TRANSMITTER_ONLINE
    - Prevents pairing attempts when receiver is full (no available slots)
    - Known transmitters will not receive MSG_ALIVE if receiver is at capacity
    [receiver.ino]
2026-01-02 Fix debug monitor communication and add comprehensive receiver debug messages
    - Fixed receiver debug monitor pairing: now sends status on first beacon after boot
    - Added statusSent flag to prevent duplicate status messages
    - Fixed debug monitor message reception: handle variable-length messages correctly
    - Added detailed debug messages for receiver events:
    * Transmitter online/offline with context (known/unknown, slots available)
    * Discovery requests with pairing success/failure reasons
    * Transmitter paired events showing removal from list
    * MSG_ALIVE events showing transmitter index
    * Improved pedal event messages
    - Fixed discovery request debug logic for known transmitters (recon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
2026-01-02 Split documentation: README for overview, INSTRUCTIONS for detailed setup
    - README.md: Concise project overview, features, quick start
    - INSTRUCTIONS.md: Complete setup, wiring, configuration, troubleshooting
    - Improved navigation with clear links between documents
    - Better presentation for GitHub project page
2026-01-02 Update hardware requirements: clarify tested boards vs compatibility
    - Changed 'Recommended' to 'Required/Tested' for accuracy
    - Specify board-specific features (pin 27 button, WS2812 LED)
    - Note that other boards need code modifications
    - Make it clear which features depend on specific hardware
2026-01-02 Add RTC memory persistence for instant resume from deep sleep
    Added:
    - RTC memory persistence for pairing state (survives deep sleep, not power cycles)
    - Transmitter restores pairing from RTC memory on wake from deep sleep
    - Instant resume with no reconnection delay or broadcast
    - Receiver adds peer immediately when pairing is restored
    - Debug messages showing RTC pairing save/restore operations
    Changed:
    - Transmitter skips MSG_TRANSMITTER_ONLINE broadcast when restored from RTC
    - Deep sleep now saves pairing state to RTC memory
    - Enhanced deep sleep debug messages with pairing state
    Result: Pedal acts as if it never went offline when waking from deep sleep
    [transmitter.ino]
2026-01-02 Improve debug output and monitoring
    - Simplified startup messages to single 'Ready' message
    - Added debug mode status to transmitter startup output
    - Send 'Ready' message immediately if already paired (not waiting for beacon)
    - Increased debug monitor serial buffer to 8192 bytes for better burst handling
    - Added inactivity timeout diagnostic logging (every 30s when debug enabled)
    Fixed:
    - Message ordering: 'Ready' is now always the first message sent
    - Prevents confusing out-of-order messages on startup
    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
    [debug-monitor.ino, transmitter.ino]
2026-01-02 Convert debug time displays from milliseconds to seconds
    - Inactivity timeout messages now show seconds with one decimal place
    - Example: '120000 ms' -> '120.0s' or '30000 ms' -> '30.0s'
    - More human-readable debug output
    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
2026-01-04 Fix deep sleep wake-up issues and improve debug monitor reliability
    - Fix first pedal press after deep sleep wake not typing (key validation issue)
    - Fix double release events after wake-up
    - Add cumulative timestamp tracking across deep sleep cycles
    - Add message queue to debug monitor to prevent message loss/corruption
    - Add validation and error logging for invalid key values
    - Rename HEARTBEAT_INTERVAL to DEBUG_STATUS_INTERVAL for clarity
    - Improve ESP-NOW peer connection timing after deep sleep
    - Add timestamps to all debug messages showing time from boot
    [debug-monitor.ino, receiver.ino, transmitter.ino]
2026-01-04 Add KiCad design rules and DRC files (.kicad_dru, .rules)
2026-01-04 Add images to PCB design documentation
2026-01-04 Add PCB design images to docs folder
2026-01-04 Add GPIO21 pedal switch to FireBeetle pinout documentation
2026-01-04 Add GPIO21 pedal switch to PCB design documentation (not FireBeetle)
2026-01-05 Update PCB design, documentation, and images
    [esp32-pedal-pcb.csv, esp32-pedal-pcb.kicad_pcb, esp32-pedal-pcb.kicad_sch]
2026-01-05 Simplify PCB README to just link images
2026-01-07 Update PCB schematics and routing, add PCBWAY directory to gitignore
    [TPS2553DBVR.step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]
2026-01-08 Remove gerber files from repository and add to gitignore
    [esp32-pedal-pcb-B_Cu.gbr, esp32-pedal-pcb-B_Mask.gbr, esp32-pedal-pcb-B_Paste.gbr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]
2026-01-08 Remove KiCad autosave files from repository
2026-01-08 Update BOM
    [esp32-pedal-pcb.csv]
2026-01-08 Add README for PanicPedal Pro transmitter PCB
2026-01-08 Add automatic switch detection for PanicPedal Pro using NC contacts
    - Add GPIO45 and GPIO46 definitions for NC contacts
    - Implement detectPedalMode() function to auto-detect connected switches
    - Automatically set pedal mode based on detected switches:
    - Both switches connected -> Dual mode
    - Only first switch connected -> Single mode
    - Remove need to hardcode pedal configuration
    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
2026-01-08 Store detected pedal mode in NVRAM for PanicPedal Pro
    - Add Preferences library for NVS storage
    - Store detected pedal mode in NVS on first boot
    - Load stored mode from NVS on subsequent boots
    - Detection runs only once until firmware is reflashed
    - Prevents re-detection on every boot for better reliability
    [panicpedal-pro.ino]
2026-01-08 Change PanicPedal Pro to detect pedals on every boot
    - Remove NVS storage for pedal mode
    - Remove firmware version checking
    - Run pedal detection on every boot instead of storing
    - Simplifies code and ensures correct configuration even if switches change
    - Update README to reflect new behavior
    [panicpedal-pro.ino]
2026-01-08 Update GPIO pin references in comments and debug output
2026-01-08 Update KiCad PCB project files and backups
    [esp32-pedal-pcb.csv, esp32-pedal-pcb.kicad_pcb, esp32-pedal-pcb.kicad_sch]
2026-01-09 Update PanicPedal Pro GPIO pin assignments
    - GPIO1: Pedal Left NO (unchanged)
    - GPIO2: Pedal Right NO (unchanged)
    - GPIO3: Battery voltage sensing (unchanged)
    - GPIO4: STAT1/LBO from MCP73871 (unchanged)
    - GPIO5: SPDT switch position 1 (unchanged)
    - GPIO6: SPDT switch position 2 (unchanged)
    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
2026-01-09 Update README to document LED control implementation
2026-01-09 Update README with new LED behavior (off after pairing, only on when charging)
